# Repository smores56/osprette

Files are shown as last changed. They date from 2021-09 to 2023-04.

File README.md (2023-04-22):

The Osprette
============

This repo contains design files for the PCB and case of my variation on Brow's
[Balbuzard][balbuzard]. The keyboard is a 34 key unibody that uses any pro-micro
compatible daughterboard. It comes with bluetooth support by way of battery
terminals and a power switch.

# Inspiration

I am a big fan of the [Balbuzard][balbuzard], especially the secret choc version that
Brow sent to me. However, there were some things I wanted to change:

- The halves are too close together: not by much, but a little extra space helps a lot
- The thumbs are uncomfortable: normal choc V1 keycaps have ridges on the edges, so the sideways thumbs hurt after prolonged use
- There are too many keys: I've been using 34 keys happily for a while and don't need the other 4 thumb keys
- Not-aggressive pinky stagger: The pinkies on the original are very Corne staggered, which is fine, but I've been spoiled lately by more comfortable, radical stagger
- No support for a power switch: bluetooth is great when you can afford a compatible MCU, and I wanna throw this thing in a bag without worrying about keypresses

All these things together make this board my next step in pursuing the best 34-key
keeb with comfortable pinkies.

# Ordering One

To order one of these from JLC, just upload the `osprette.zip` archive in the
`pcb` directory to the Order Now page at jlcpcb.com, and make sure to set a 1.6mm
thickness.

# Pictures

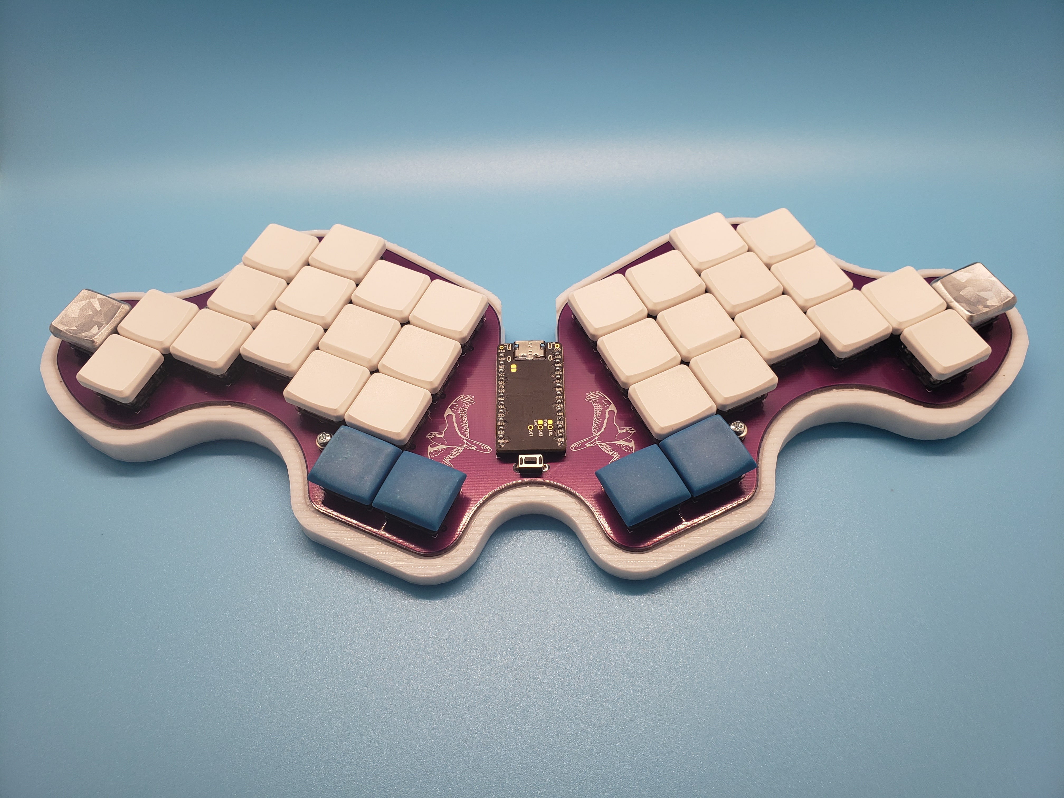
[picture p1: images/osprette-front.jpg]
Osprette from the front

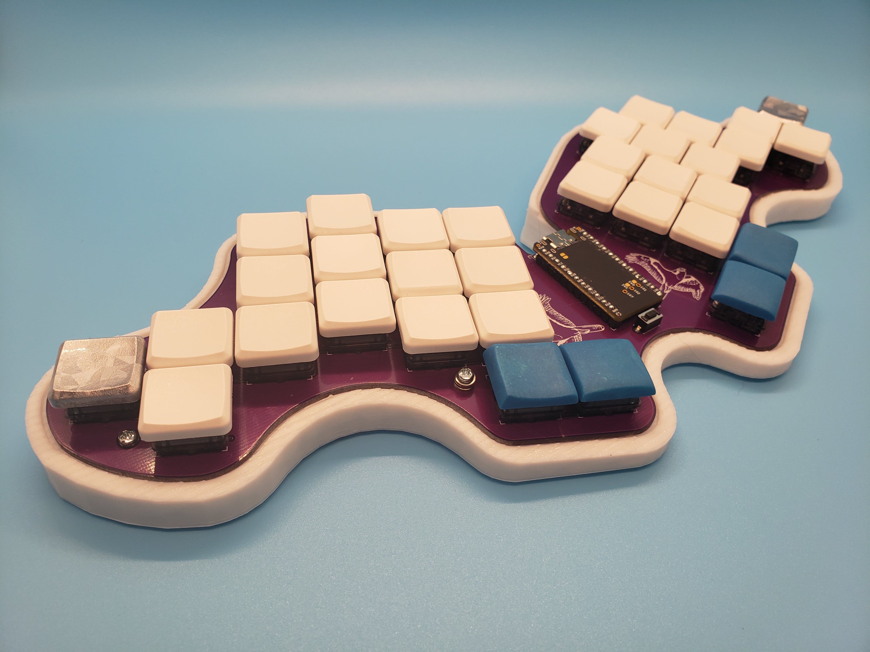
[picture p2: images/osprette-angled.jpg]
Osprette from an angle

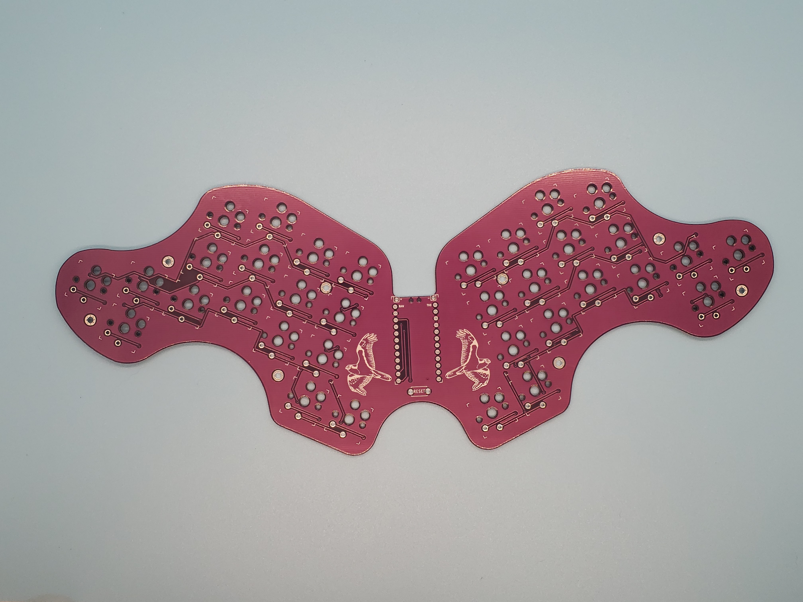
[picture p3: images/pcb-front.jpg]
PCB front


[balbuzard]: https://github.com/brow/balbuzard

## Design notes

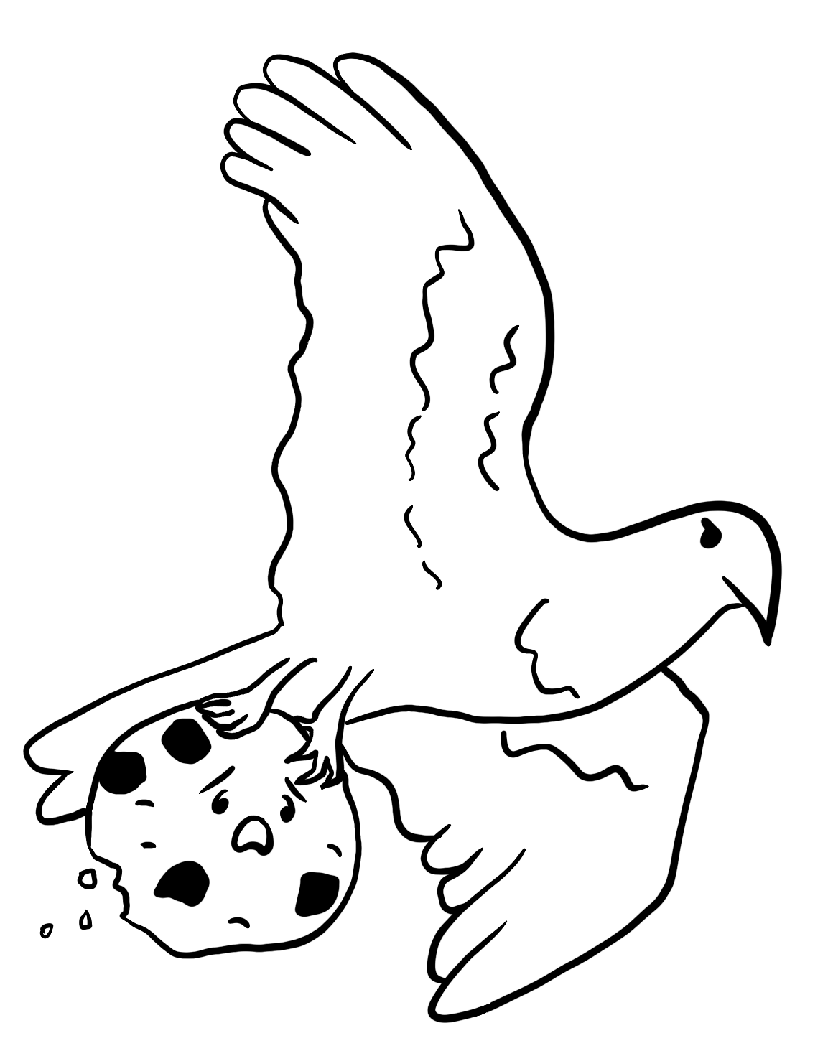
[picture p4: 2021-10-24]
art/bird.png

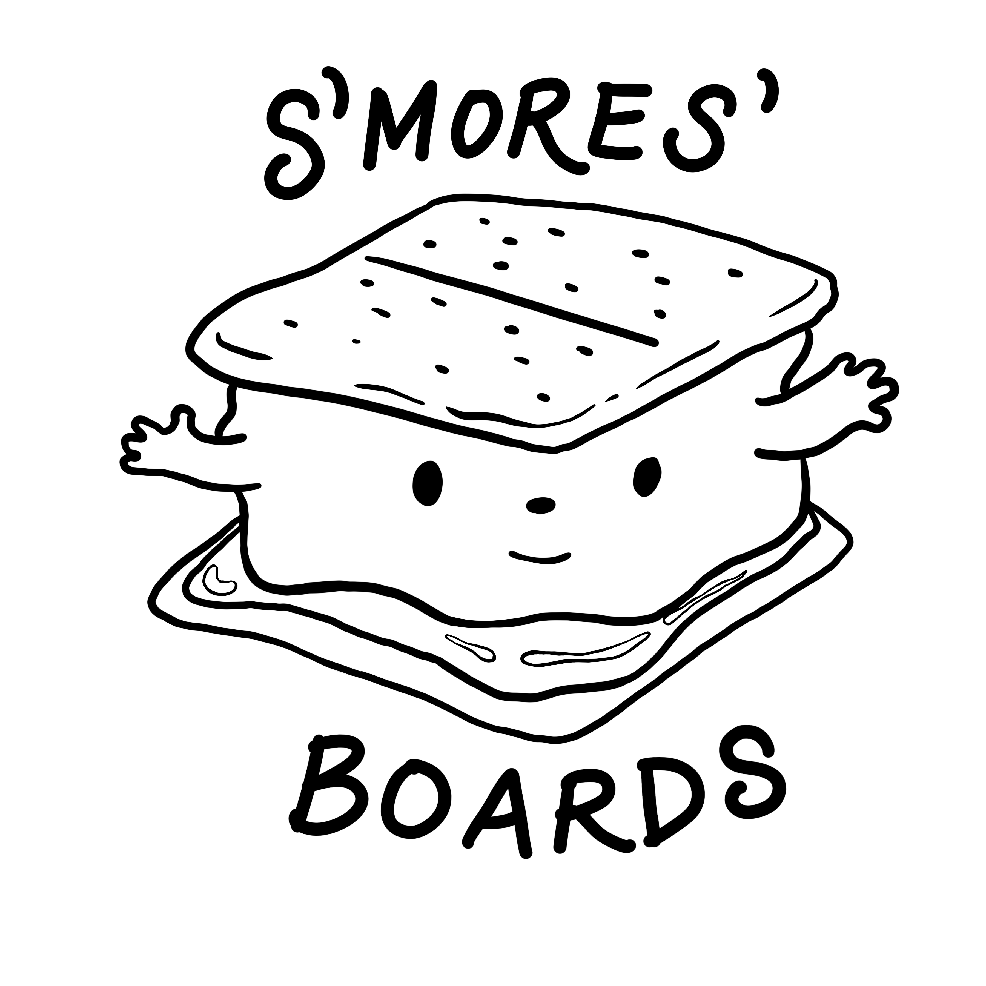
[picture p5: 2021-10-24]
art/smores.png

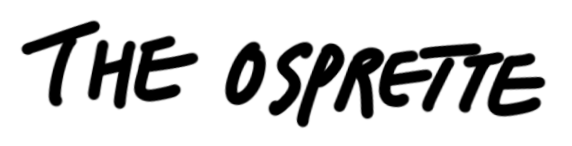
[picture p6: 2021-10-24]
art/text.png

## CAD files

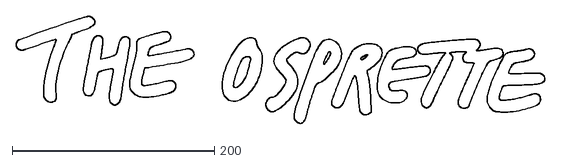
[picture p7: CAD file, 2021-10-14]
art/text.dxf
523.1 x 106.2

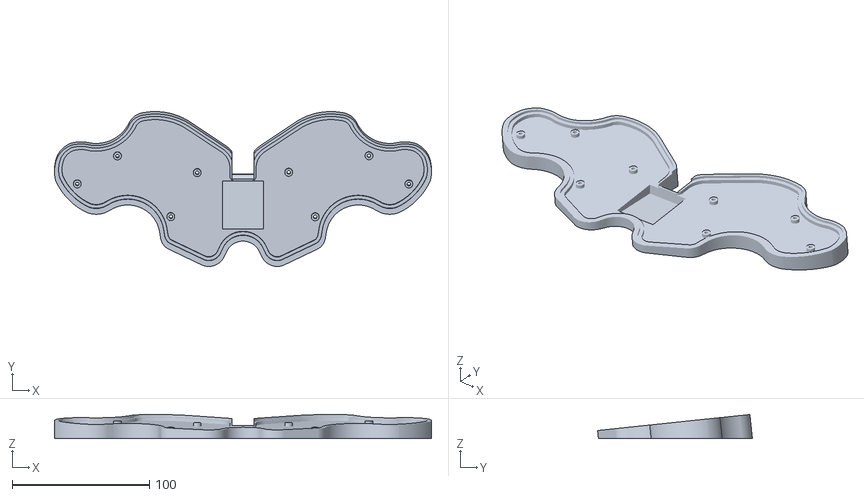
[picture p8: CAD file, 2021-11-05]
case/osprette.stl
274.8 x 112.9 x 17.5

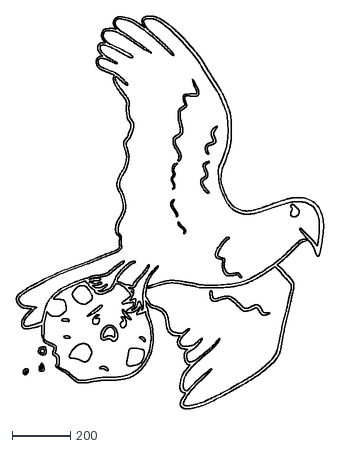
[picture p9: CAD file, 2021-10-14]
art/bird.dxf
1056.4 x 1350.7

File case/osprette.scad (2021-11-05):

pcb_thickness = 1.6;
pcb_inner_margin = 1.5;
pcb_outer_margin = 1;

battery_width = 30;
battery_height = 35;
battery_thickness = 5;

case_height = 12;
case_thickness = 1.5;
component_thickness = 2.5;
shell_margin = 3;

tilt_angle = 6;

mounting_hole_diameter = 2.5;
mounting_hole_locations = [
    [33.4, 8.7], [-33.3, 9],
    [52.6, -23.5], [-52.6, -23.6],
    [91.5, 21], [-91.8, 21.1],
    [120.8, 0.5], [-120.9, 0.4]
];

module dxf_layer(name) {
    translate([-148.739, 100, 0])
    import("osprette.dxf", layer=name, center=true, $fn=400);
}

module pcb() dxf_layer("Edge");
module components() dxf_layer("BFab");
module holes() dxf_layer("FCrtYd");

module orient_to_top_of_case() {
    translate([0, 0, case_height])
    rotate([180 - tilt_angle, 0, 180])
    children();
}

module shell() {
    rotate([180 - tilt_angle, 0, 180])
    linear_extrude(case_height * 2, center=true)
    offset(delta=(pcb_outer_margin + shell_margin))
    pcb();
}

module component_tray() {
    orient_to_top_of_case()
    linear_extrude(2 * (pcb_thickness + component_thickness), center=true)
    offset(delta=-pcb_inner_margin)
    pcb();
}

module pcb_tray() {
    orient_to_top_of_case()
    linear_extrude(2 * pcb_thickness, center=true)
    offset(delta=pcb_outer_margin)
    pcb();
}

module battery_cutout() {
    translate([0, -14.5, case_thickness])
    linear_extrude(case_height * 2, center=false)
    square([battery_width, battery_height], center=true);
}

module usb_cutout() {
    orient_to_top_of_case()
    linear_extrude((pcb_thickness + 1.5) * 2, center=true)
    square([16, 50], center=true);
}

module finger_cutout() {
    orient_to_top_of_case()
    translate([0, 16.8, 5])
    linear_extrude(case_height * 2, center=true)
    square([16, 20], center=true);
}

module power_switch_cutout() {
    rotate([tilt_angle, 0, 0])
    rotate([0, 90, 0])
    linear_extrude(16, center=true)
    offset(delta=5, chamfer=true)
    translate([-11.5, 12.2, 0])
    square(4, center=true);
}

module mounting_hole_struts() {
    for (location = mounting_hole_locations) {
        orient_to_top_of_case()
        translate([location[0], location[1], pcb_thickness])
        linear_extrude(component_thickness, center=false)
        circle(2.85, $fn=100);
    }
}

module mounting_drill_holes() {
    for (location = mounting_hole_locations) {
        orient_to_top_of_case()
        translate([location[0], location[1], 1])
        linear_extrude(case_height, center=false)
        circle(1.3, $fn=100);
    }
}

module mounting_hole_countersinks() {
    for (location = mounting_hole_locations) {
        orient_to_top_of_case()
        translate([location[0], location[1], pcb_thickness + component_thickness + case_thickness + 1])
        linear_extrude(case_height * 4, center=false)
        circle(3.5, $fn=100);
        
    }
}

%
orient_to_top_of_case()
linear_extrude(pcb_thickness)
pcb();

difference() {
    union() {
        intersection() {
            difference() {
                shell();
                pcb_tray();
                component_tray();
                battery_cutout();
                usb_cutout();
                finger_cutout();
                power_switch_cutout();
                mounting_hole_countersinks();
            };
            translate([0, 0, 500])
            cube(1000, center=true);
        };
        mounting_hole_struts();
    };
    mounting_drill_holes();
};

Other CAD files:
case/osprette.dxf

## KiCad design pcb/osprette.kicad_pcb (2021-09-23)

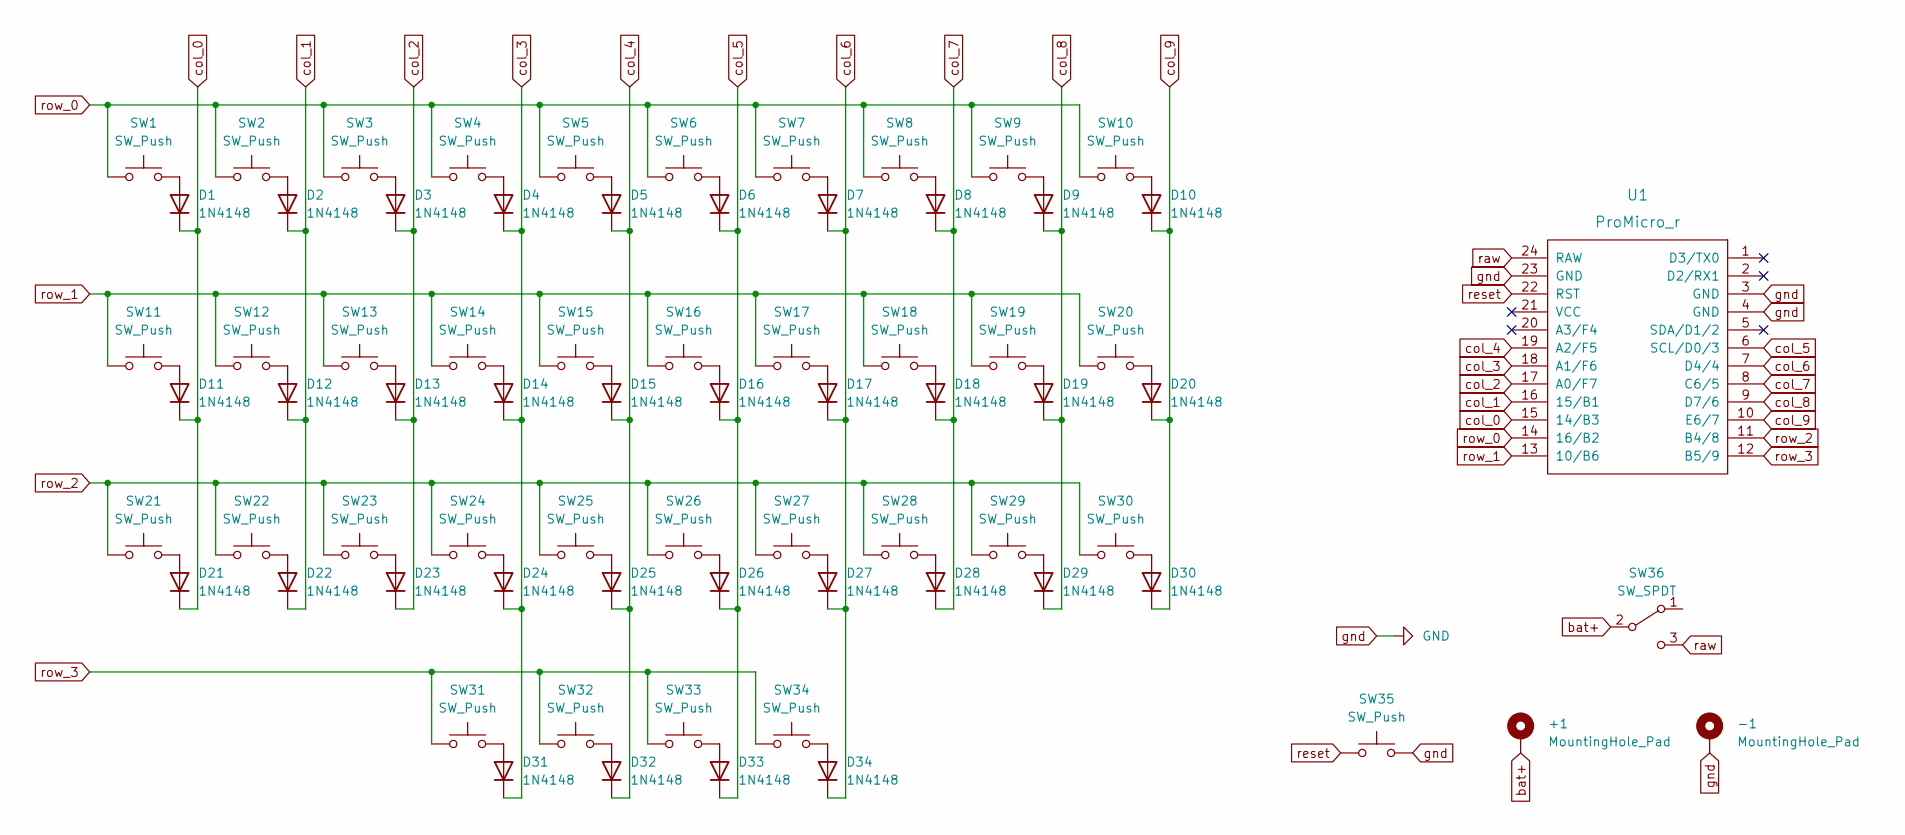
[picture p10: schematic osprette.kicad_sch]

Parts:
+1: MountingHole_Pad; 1pin_conn
-1: MountingHole_Pad; 1pin_conn
D1, D2, D3, D4, D5, D6, D7, D8, D9, D10, D11, D12, D13, D14, D15, D16, D17, D18, D19, D20, D21, D22, D23, D24, D25, D26, D27, D28, D29, D30, D31, D32, D33, D34: 1N4148; D_SOD-123
SW1, SW2, SW3, SW4, SW5, SW6, SW7, SW8, SW9, SW10, SW11, SW12, SW13, SW14, SW15, SW16, SW17, SW18, SW19, SW20, SW21, SW22, SW23, SW24, SW25, SW26, SW27, SW28, SW29, SW30, SW31, SW32, SW33, SW34: SW_Push; Kailh_socket_PG1350_optional
SW35: SW_Push; ResetSW
SW36: SW_SPDT; SW_SPDT_PCM12
U1: ProMicro_r; ProMicro_v3.5

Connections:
unnamed: D1.2 (A), SW1.2
unnamed: D2.2 (A), SW2.2
unnamed: D3.2 (A), SW3.2
unnamed: D4.2 (A), SW4.2
unnamed: D5.2 (A), SW5.2
unnamed: D6.2 (A), SW6.2
unnamed: D7.2 (A), SW7.2
unnamed: D8.2 (A), SW8.2
unnamed: D9.2 (A), SW9.2
unnamed: D10.2 (A), SW10.2
unnamed: D11.2 (A), SW11.2
unnamed: D12.2 (A), SW12.2
unnamed: D13.2 (A), SW13.2
unnamed: D14.2 (A), SW14.2
unnamed: D15.2 (A), SW15.2
unnamed: D16.2 (A), SW16.2
unnamed: D17.2 (A), SW17.2
unnamed: D18.2 (A), SW18.2
unnamed: D19.2 (A), SW19.2
unnamed: D20.2 (A), SW20.2
unnamed: D21.2 (A), SW21.2
unnamed: D22.2 (A), SW22.2
unnamed: D23.2 (A), SW23.2
unnamed: D24.2 (A), SW24.2
unnamed: D25.2 (A), SW25.2
unnamed: D26.2 (A), SW26.2
unnamed: D27.2 (A), SW27.2
unnamed: D28.2 (A), SW28.2
unnamed: D29.2 (A), SW29.2
unnamed: D30.2 (A), SW30.2
unnamed: D31.2 (A), SW31.2
unnamed: D32.2 (A), SW32.2
unnamed: D33.2 (A), SW33.2
unnamed: D34.2 (A), SW34.2
bat+: +1.1, SW36.2 (B); also elsewhere on the board
col_0: D1.1 (K), D11.1 (K), D21.1 (K), U1.15 (14/B3)
col_1: D2.1 (K), D12.1 (K), D22.1 (K), U1.16 (15/B1)
col_2: D3.1 (K), D13.1 (K), D23.1 (K), U1.17 (A0/F7)
col_3: D4.1 (K), D14.1 (K), D24.1 (K), D31.1 (K), U1.18 (A1/F6)
col_4: D5.1 (K), D15.1 (K), D25.1 (K), D32.1 (K), U1.19 (A2/F5)
col_5: D6.1 (K), D16.1 (K), D26.1 (K), D33.1 (K), U1.6 (SCL/D0/3)
col_6: D7.1 (K), D17.1 (K), D27.1 (K), D34.1 (K), U1.7 (D4/4)
col_7: D8.1 (K), D18.1 (K), D28.1 (K), U1.8 (C6/5)
col_8: D9.1 (K), D19.1 (K), D29.1 (K), U1.9 (D7/6)
col_9: D10.1 (K), D20.1 (K), D30.1 (K), U1.10 (E6/7)
gnd: -1.1, SW35.2, U1.3 (GND), U1.4 (GND), U1.23 (GND); also elsewhere on the board
raw: SW36.3 (C), U1.24 (RAW)
reset: SW35.1, U1.22 (RST)
row_0: SW1.1, SW2.1, SW3.1, SW4.1, SW5.1, SW6.1, SW7.1, SW8.1, SW9.1, SW10.1, U1.14 (16/B2)
row_1: SW11.1, SW12.1, SW13.1, SW14.1, SW15.1, SW16.1, SW17.1, SW18.1, SW19.1, SW20.1, U1.13 (10/B6)
row_2: SW21.1, SW22.1, SW23.1, SW24.1, SW25.1, SW26.1, SW27.1, SW28.1, SW29.1, SW30.1, U1.11 (B4/8)
row_3: SW31.1, SW32.1, SW33.1, SW34.1, U1.12 (B5/9)

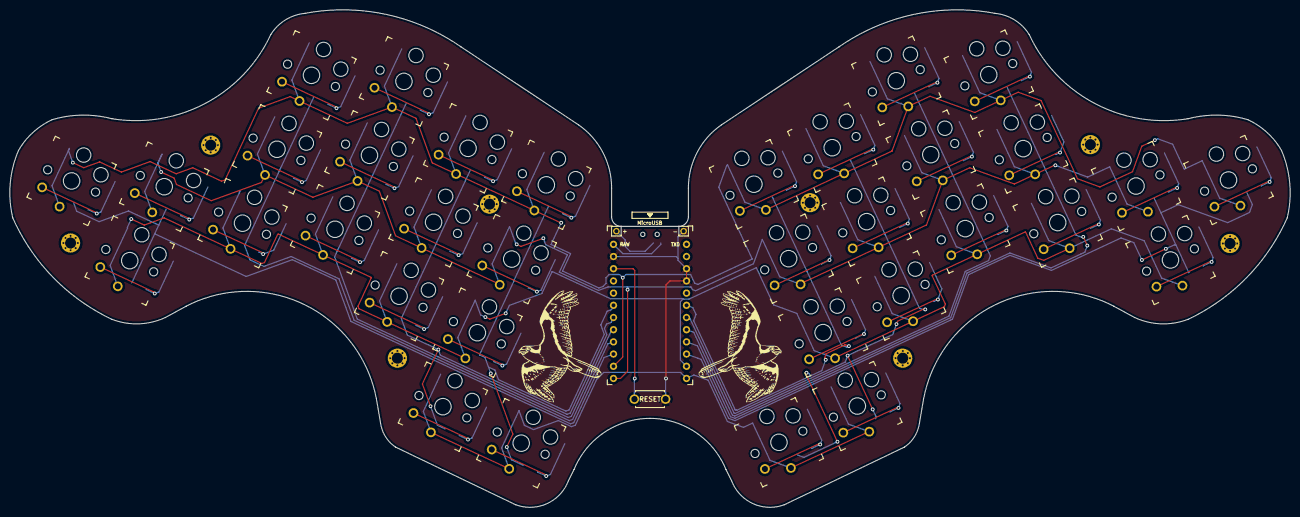
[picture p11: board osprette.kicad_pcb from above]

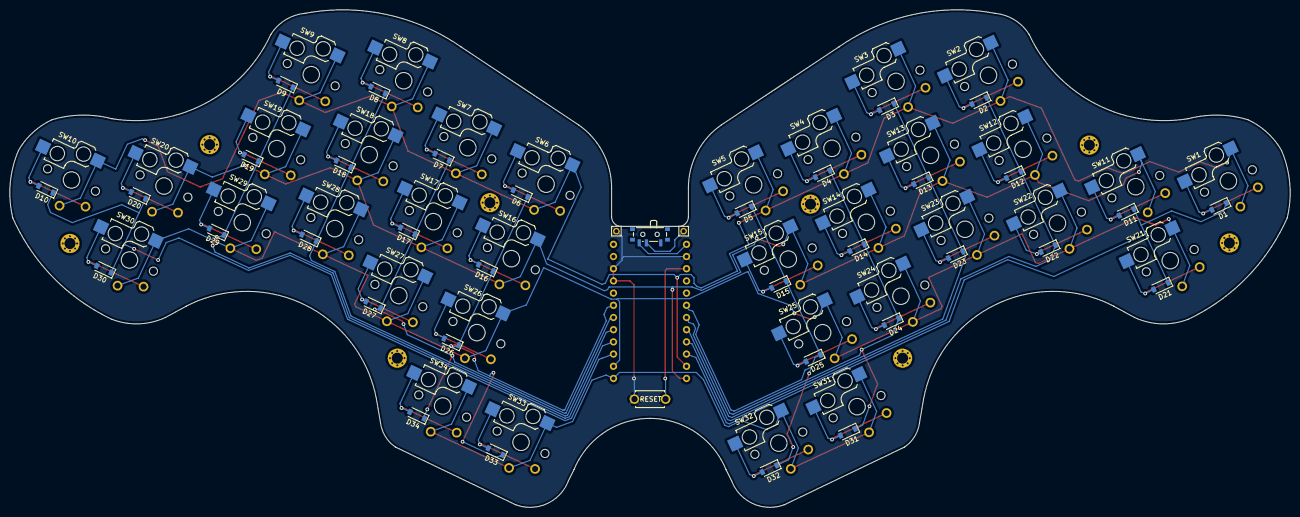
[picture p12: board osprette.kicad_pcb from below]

Board: 2 copper layers, 266.8 x 103.7 mm, 81 parts (35 on the bottom side), 52 nets.

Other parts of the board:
+: MountingHole_Pad; 1pin_conn
-: MountingHole_Pad; 1pin_conn
Ref**: Val**; M2_HOLE_v3
Ref**#2, Ref**#3, Ref**#4, Ref**#5, Ref**#6, Ref**#7, Ref**#8: Val**; M2_HOLE_v3

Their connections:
bat+: +.1; also elsewhere on the board
gnd: -.1; also elsewhere on the board

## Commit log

2021-09-23 finalize design, add silk
    [osprette.kicad_pcb, osprette.kicad_sch, osprey.dxf]
2021-09-25 finish case, add readme
    [osprette.dxf, osprette.kicad_pcb, osprette.kicad_sch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]
2021-09-27 use offset for cleaner case brim, add better battery area
    [osprette.scad, osprette.stl]
2021-09-28 widen usb aperture, strengthen struts
    [osprette.scad, osprette.stl]
2021-10-14 update art, remove copper islands, cleanup case
    [bird.dxf, osprette.scad, osprette.stl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]
2021-10-24 update art to be rendered correctly
    [smores.dxf]
2021-11-05 re-thicken mounting structure
    [osprette.scad, osprette.stl]
2026-10-18 refactor: restructure into the Osprette family repo
    Fold the per-revision repos (osprette-v2, -v3, -mx, osprangle, roadkill)
    into subdirs, move V1 to v1/, add a family README, drop committed KiCad
    junk, and give the repo a single LICENSE.
2026-10-18 docs: add board photos and wire them into the READMEs
2026-10-18 docs: clean up board READMEs, credits, and image metadata
    Correct the V1 opener, widen the license years, credit Sadek Baroudi
    for the MX case, point the sephirette link at the clog family repo, and
    strip GPS metadata from the board photos. Drop the inert per-board
    .gitmodules files, which git never reads.
